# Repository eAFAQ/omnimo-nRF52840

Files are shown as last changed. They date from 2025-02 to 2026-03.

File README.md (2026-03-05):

# Omnimo nRF52840

Welcome to the Omnimo nRF52840 repository, a compact development board powered by Nordic's nRF52840 multiprotocol SoC. Follow the board's crowdfunding journey on [Crowd Supply](https://www.crowdsupply.com/eafaq/omnimo-nrf52840) to learn more.
<p align="center">
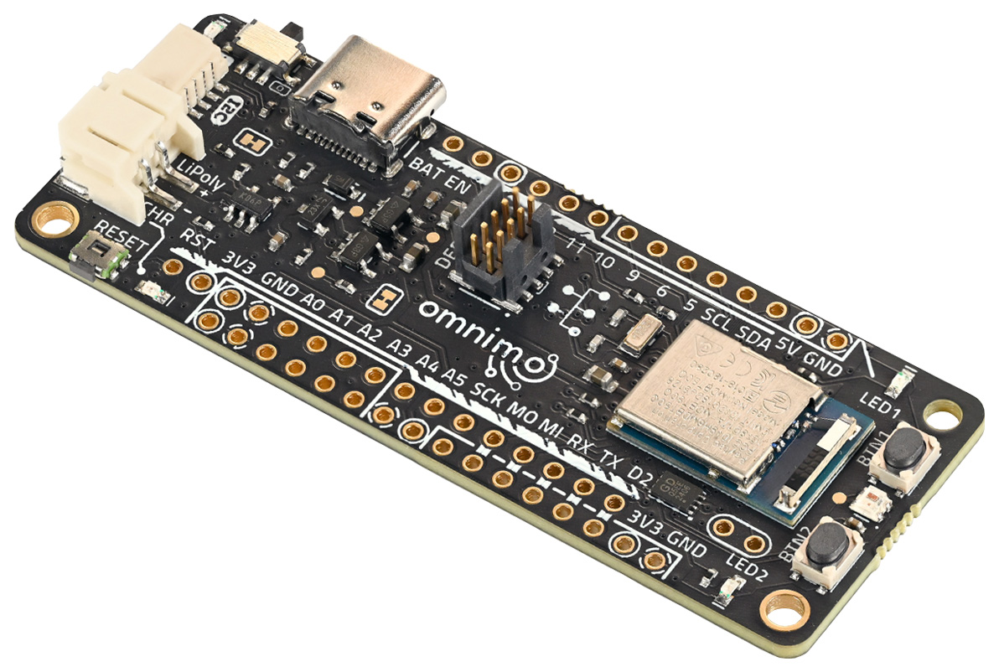
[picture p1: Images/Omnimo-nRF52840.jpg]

</p>

## Features & Specifications
- Based on Nordic Semiconductor's nRF52840 (MDBT50Q-1MV2)
  - Multi-protocol: Bluetooth LE, Bluetooth Mesh, Thread, Zigbee, NFC, ANT and 2.4 GHz proprietary protocols
  - 1 MB Flash and 256KB RAM
  - Interfaces: SPI, UART, I2C, I2S and USB
  - 12-bit, 200 KSPS ADC - 8 channels
  - 4 PWM channels
  - On-chip NFC-A tag for simplified pairing and payment solutions

<p align="center">
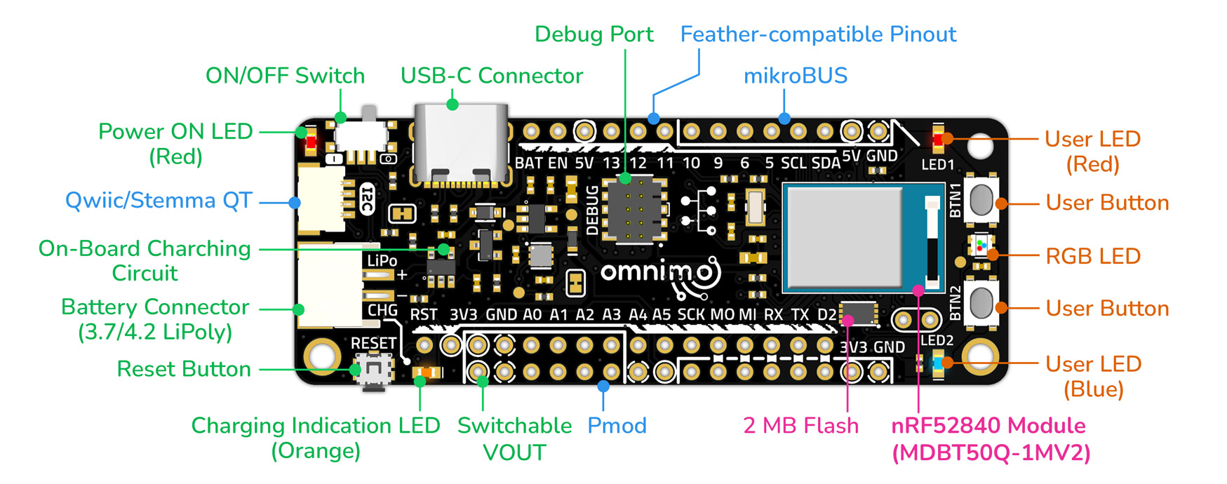
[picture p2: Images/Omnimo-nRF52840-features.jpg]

</p>

### Interfaces
- 26 GPIO pins, Feather-compatible layout
- mikroBUS
- Pmod
- Qwiic/Stemma QT
### Programming
- Three programming options: USB, SWD debug connector, and OTA
- Supported programming tools: Arduino IDE, CircuitPython, and Nordic nRF Connect SDK
- 2 MB of QSPI Flash for storing CircuitPython files
### Power
- Battery connector to connect 3.7-4.2 V Lithium-polymer battery
- On-board 3.3 V voltage regulator
- Switchable output voltage (3.3 V) to turn off modules when not in use
### Buttons and Indicators
- Side on/off switch
- 2 user-programmable LEDs
- 1 NeoPixel RGB LED
- 2 user-programmable buttons
- Side reset button

## Pinout
<p align="center">
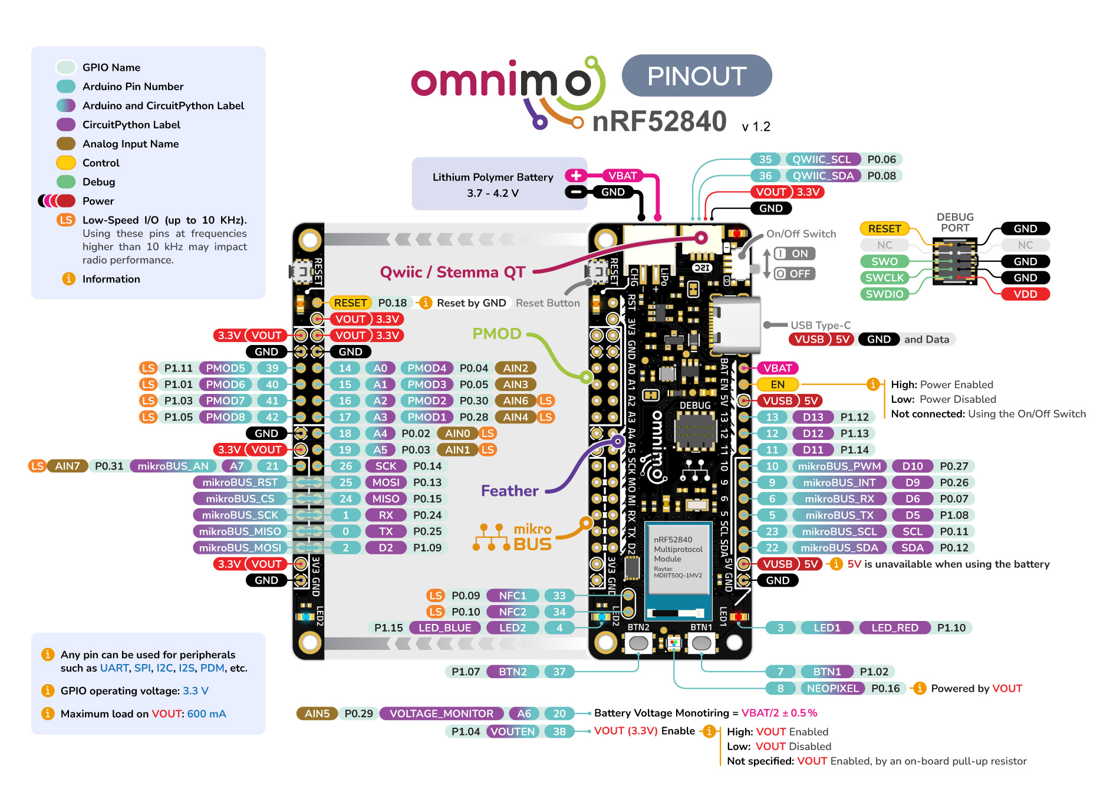
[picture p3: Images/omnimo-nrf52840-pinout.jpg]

</p>

## CircuitPython
Omnimo nRF52840 is officially supported by [CircuitPython](https://circuitpython.org/board/omnimo_nrf52840/).

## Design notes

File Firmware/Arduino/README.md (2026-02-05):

# Omnimo nRF52840 Board Variant Definitions for the Adafruit nRF52 Arduino Core

The following instructions explain how to add support for the **Omnimo nRF52840** to the **Adafruit nRF52 Arduino core**. This enables the Omnimo nRF52840 to be selected and programmed directly from the **Arduino IDE**.

## Installation Instructions

To add support for the Omnimo nRF52840 to the Adafruit nRF52 Arduino core, make sure the core is installed first. Then, one existing file must be modified and one new folder must be added:

- Modify the `boards.txt` file

- Copy the folder `variants/omnimo_nrf52840`

## 1. Install the Adafruit nRF52 Arduino Core (If Not Installed)

1. Open the Arduino IDE.

2. Go to File → Preferences.

3. In the Additional Boards Manager URLs field, add the following URL (if it is not already present):  
`https://adafruit.github.io/arduino-board-index/package_adafruit_index.json`

4. Click OK.

5. Go to Tools → Board → Boards Manager.

6. Search for Adafruit nRF52.

7. Install “Adafruit nRF52 Boards”.

## 2. Locate the Adafruit nRF52 Core Installation

If the core was installed using the Arduino Boards Manager, it is typically located in one of the following directories:

- **Windows:**  
`%LOCALAPPDATA%\Arduino15\packages\adafruit\hardware\nrf52\<version>`

- **macOS:**  
`~/Library/Arduino15/packages/adafruit/hardware/nrf52/`

- **Linux:**  
`~/.arduino15/packages/adafruit/hardware/nrf52/`

If the core was installed manually in your Arduino sketchbook, it will be located in:  
`hardware/adafruit/nrf52/`

## 3. Update the boards.txt File

1. Open the `boards.txt` file found in the directory above.

2. Scroll to the end of the file.

3. Copy and paste the contents of `eafaq_boards.txt` and append them to the bottom of `boards.txt`.

## 4. Add the Variant Folder

1. Copy the contents of the provided `variants` folder.

2. Paste them into the`variants` directory of the Adafruit nRF52 core.

No existing files should be overwritten. A new directory named variants/omnimo_nrf52840 should be added.

## Directory Contents

- **eafaq_boards.txt**  
Additional board definitions for Omnimo nRF52840

- **variants/omnimo_nrf52840**  
Board-specific definitions for Omnimo nRF52840

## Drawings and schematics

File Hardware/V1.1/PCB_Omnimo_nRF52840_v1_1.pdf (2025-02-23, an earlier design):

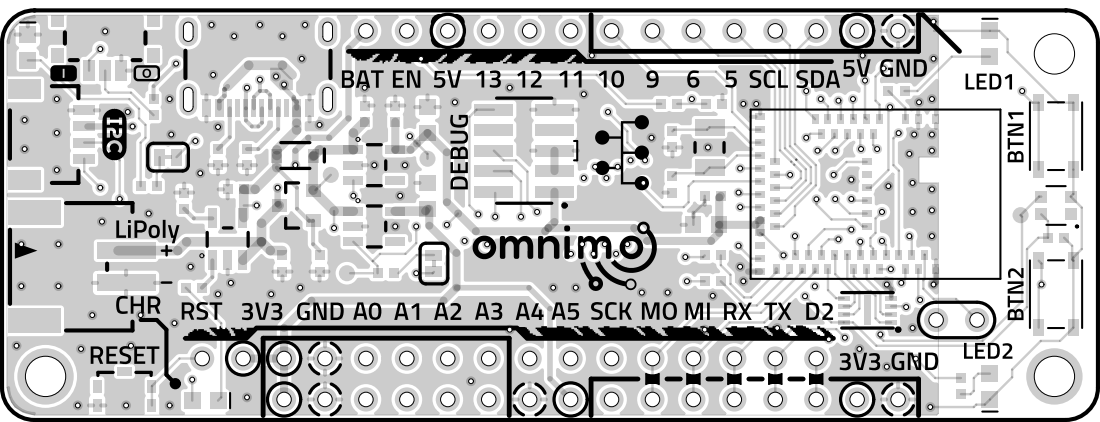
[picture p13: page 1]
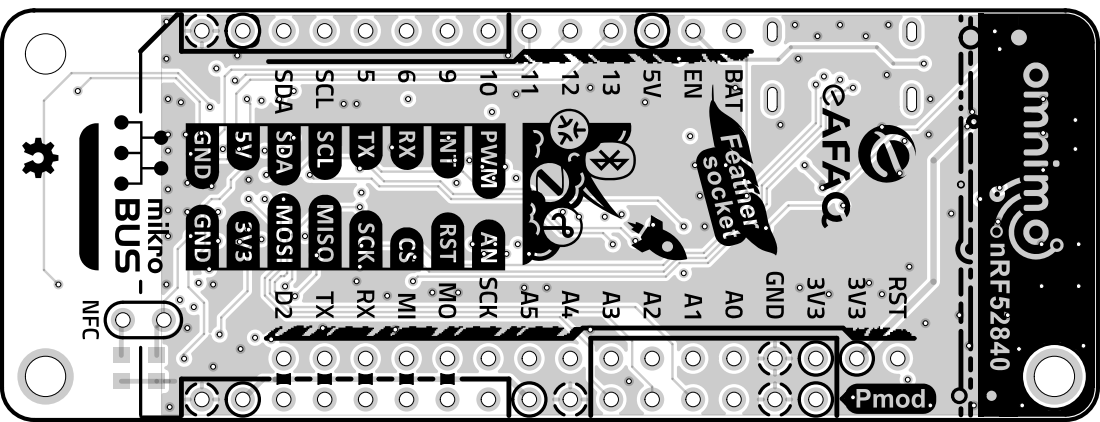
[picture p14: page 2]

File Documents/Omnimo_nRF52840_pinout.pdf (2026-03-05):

# PINOUT

# nRF52840

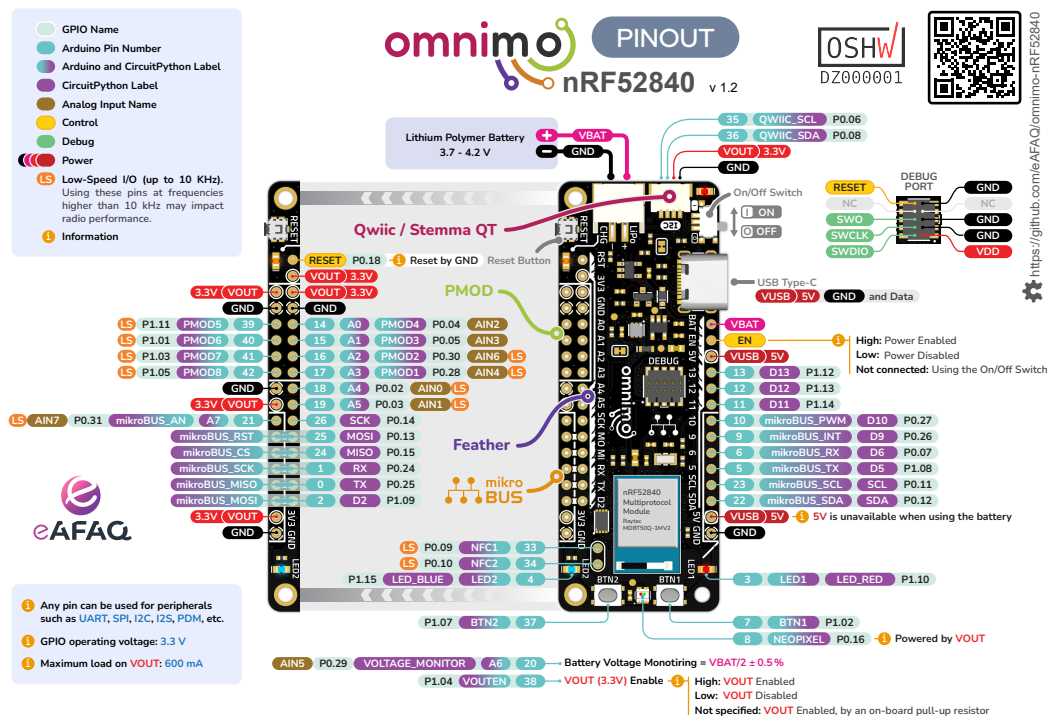
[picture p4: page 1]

https://github.com/eAFAQ/omnimo-nRF52840

GPIO Name
Arduino Pin Number
Arduino and CircuitPython Label
CircuitPython Label
Analog Input Name
Control
Debug
Power
LS Low-Speed I/O (up to 10 KHz).
Using these pins at frequencies
higher than 10 kHz may impact
radio performance.
Information

High: Power Enabled
Low: Power Disabled
Not connected: Using the On/Off Switch

i 5V is unavailable when using the battery

Any pin can be used for peripherals
such as UART, SPI, I2C, I2S, PDM, etc.
GPIO operating voltage: 3.3 V
i Maximum load on VOUT: 600 mA

Battery Voltage Monotiring = VBAT/2 ±
VOUT (3.3V) Enable

High: VOUT Enabled
Low: VOUT Disabled
Not specified: VOUT Enabled, by an on-board pull-up resistor

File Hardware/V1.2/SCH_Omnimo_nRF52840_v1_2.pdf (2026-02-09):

## Power

USB Connector | Battery Charger

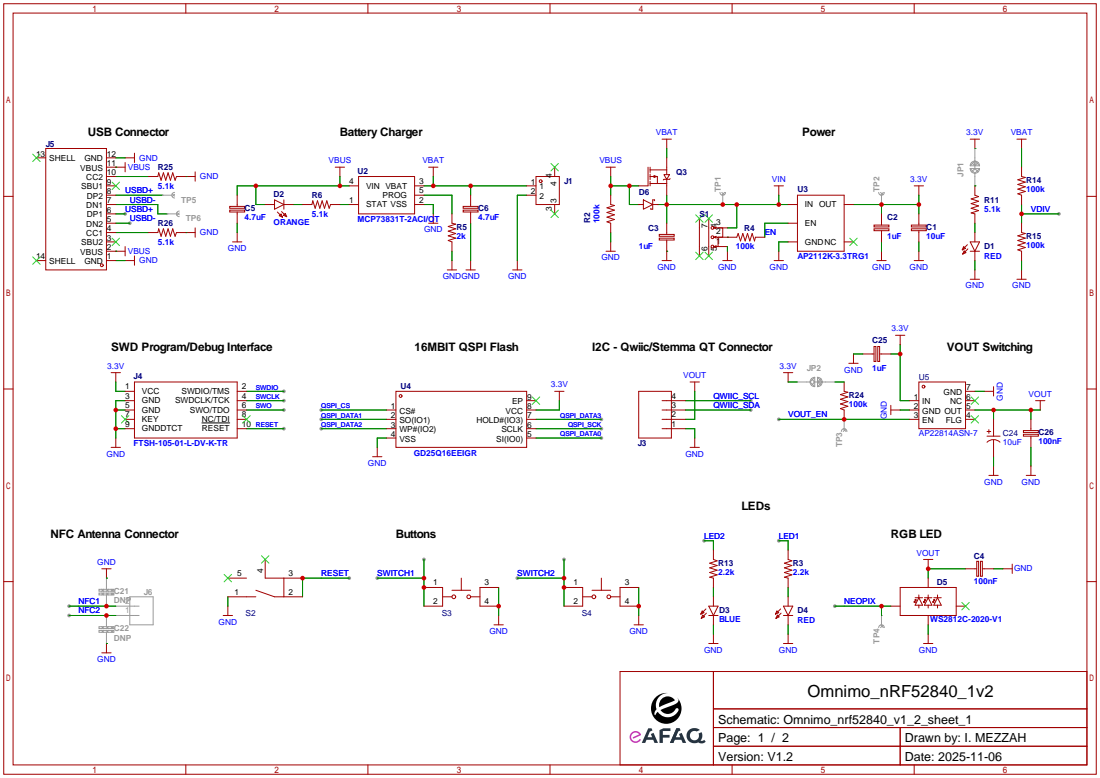
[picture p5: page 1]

SWD Program/Debug Interface

I2C - Qwiic/Stemma QT Connector

Page: 1 / 2 | Drawn by: I. MEZZAH
Version: V1.2 | Date: 2025-11-06

nRF52840 Module | Omnimo Connection Pads

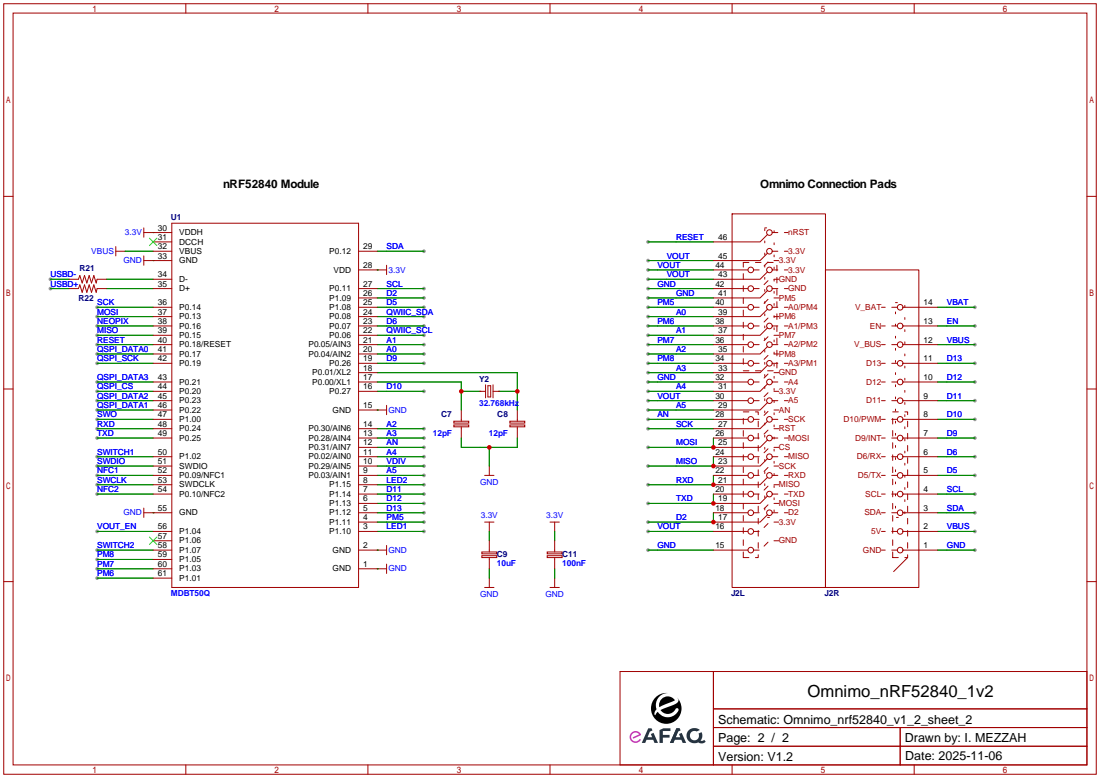
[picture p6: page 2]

Page: 2 / 2 | Drawn by: I. MEZZAH
Version: V1.2 | Date: 2025-11-06

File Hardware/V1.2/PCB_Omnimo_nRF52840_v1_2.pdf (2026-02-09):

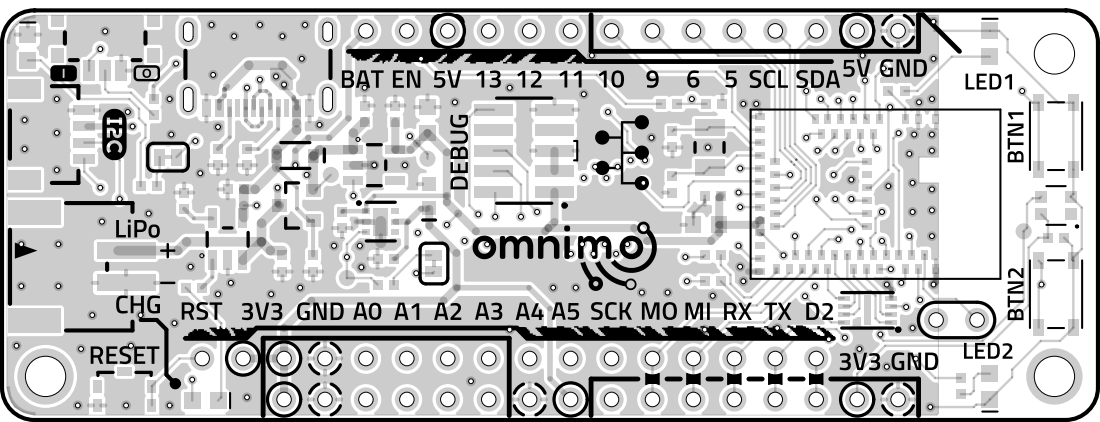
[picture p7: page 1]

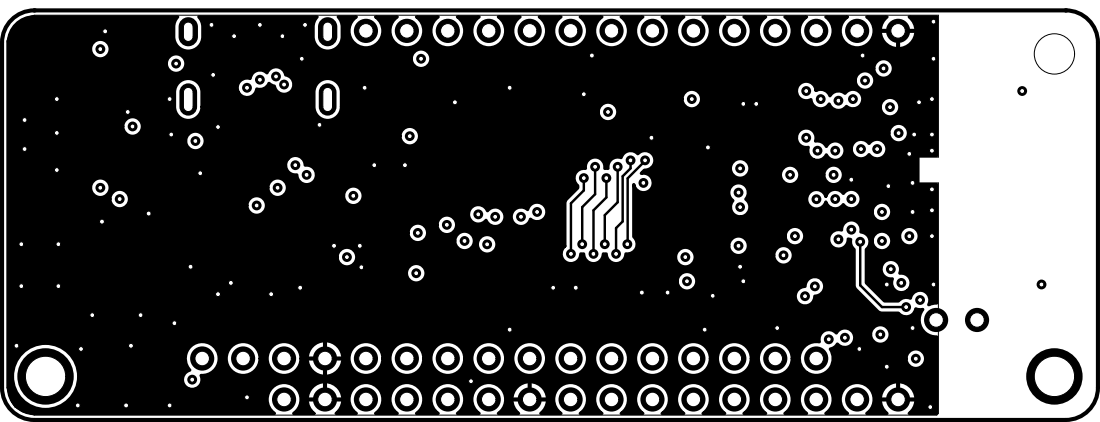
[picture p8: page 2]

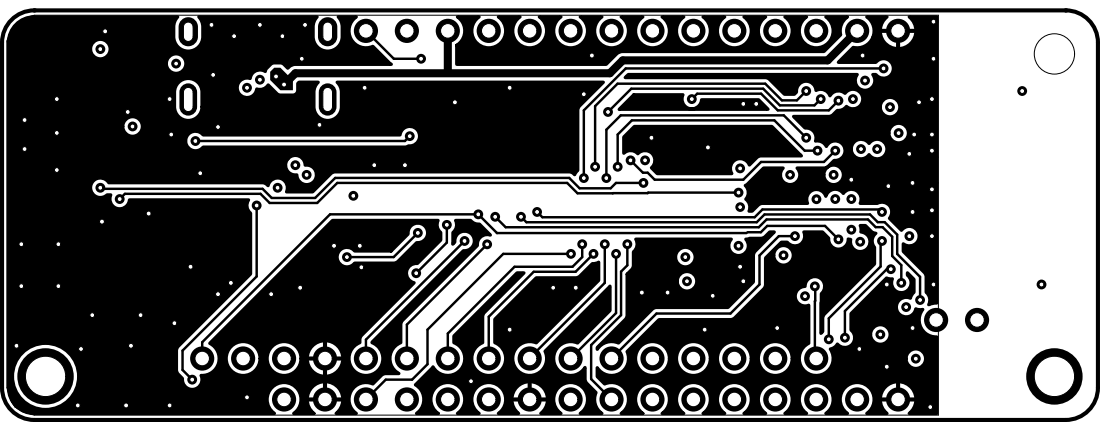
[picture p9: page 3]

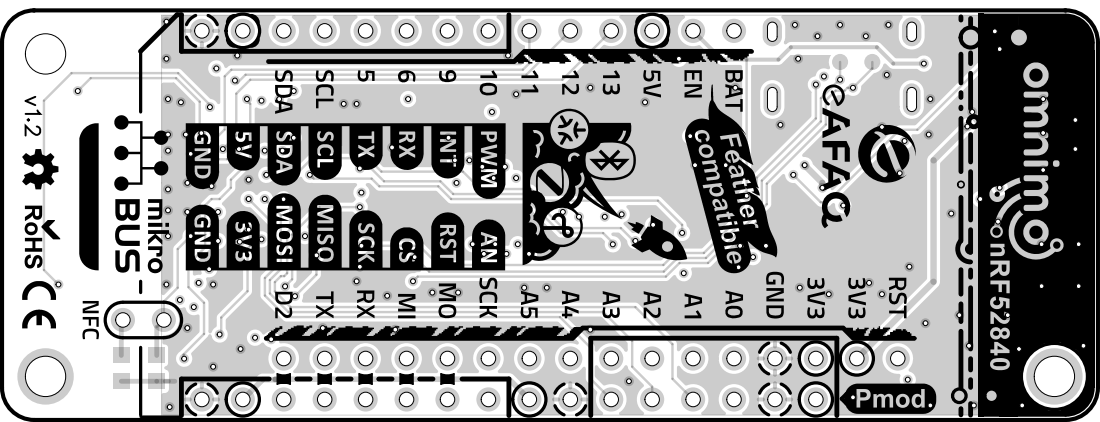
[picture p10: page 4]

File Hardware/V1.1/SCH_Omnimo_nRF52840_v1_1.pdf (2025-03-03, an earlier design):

## Power

USB Connector | Battery Charger

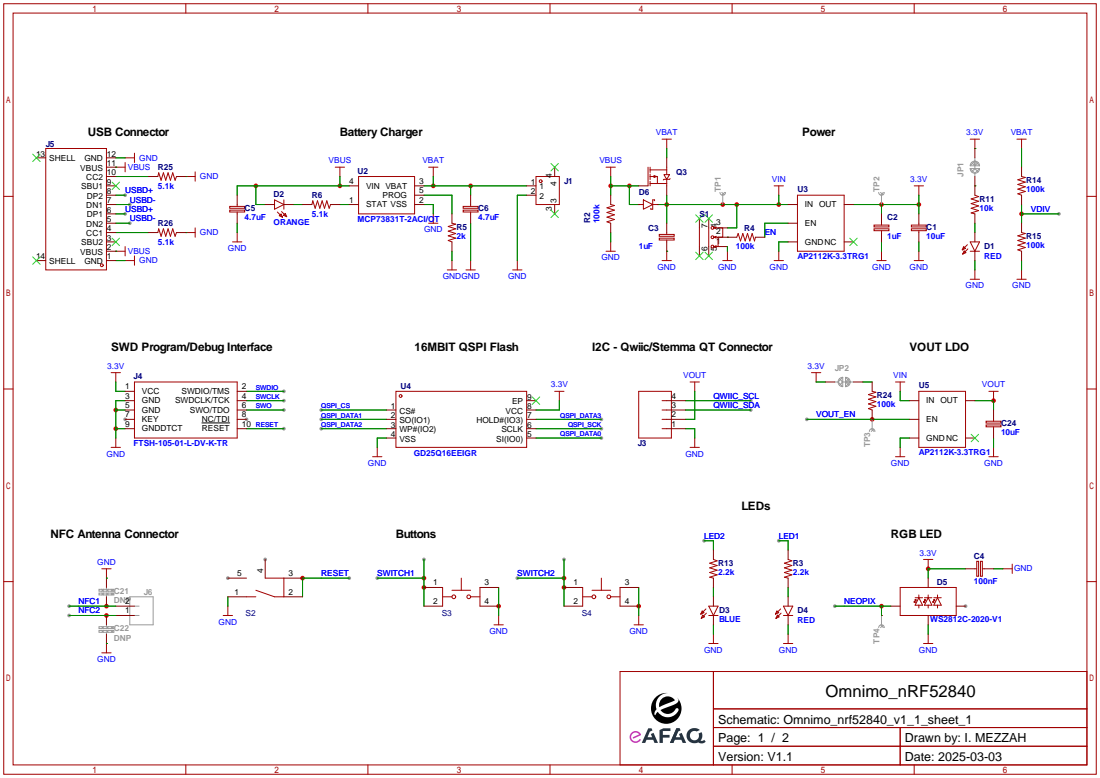
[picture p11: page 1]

SWD Program/Debug Interface

I2C - Qwiic/Stemma QT Connector

Page: 1 / 2 | Drawn by: I. MEZZAH
Version: V1.1 | Date: 2025-03-03

nRF52840 Module | Omnimo Connection Pads

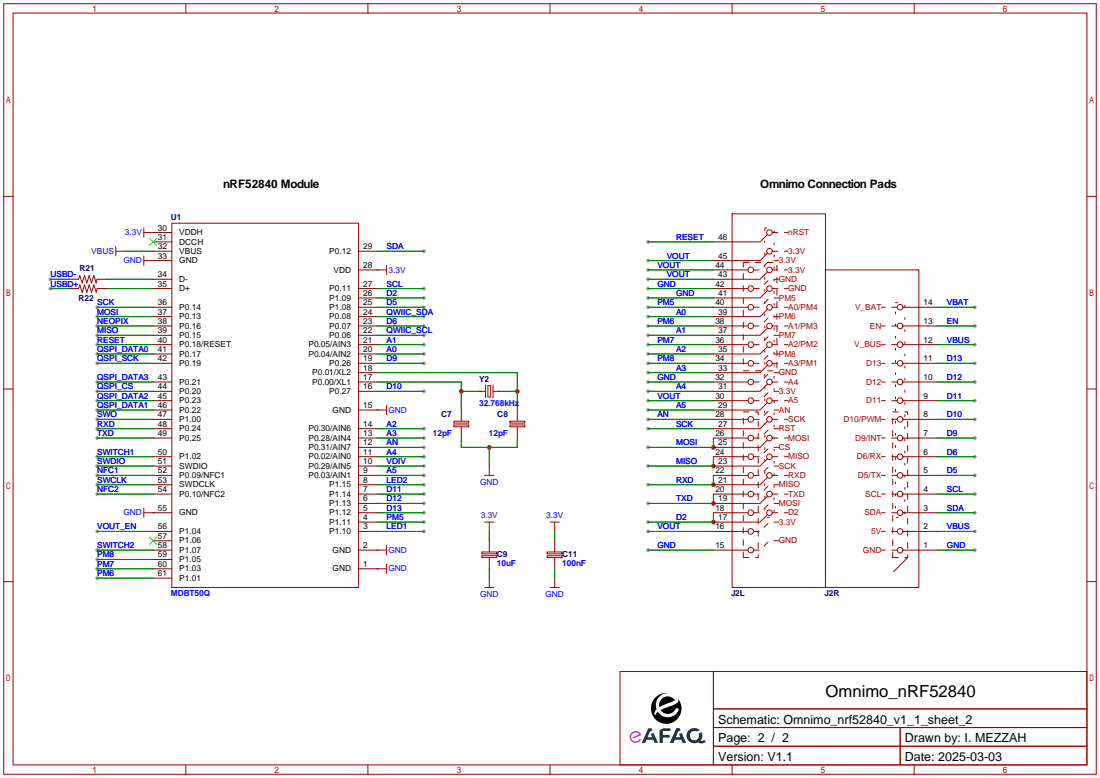
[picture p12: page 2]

Page: 2 / 2 | Drawn by: I. MEZZAH
Version: V1.1 | Date: 2025-03-03
